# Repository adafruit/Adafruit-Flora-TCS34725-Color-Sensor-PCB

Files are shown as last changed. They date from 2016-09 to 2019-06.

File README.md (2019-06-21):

## Adafruit Flora TCS34725 Color Sensor PCB

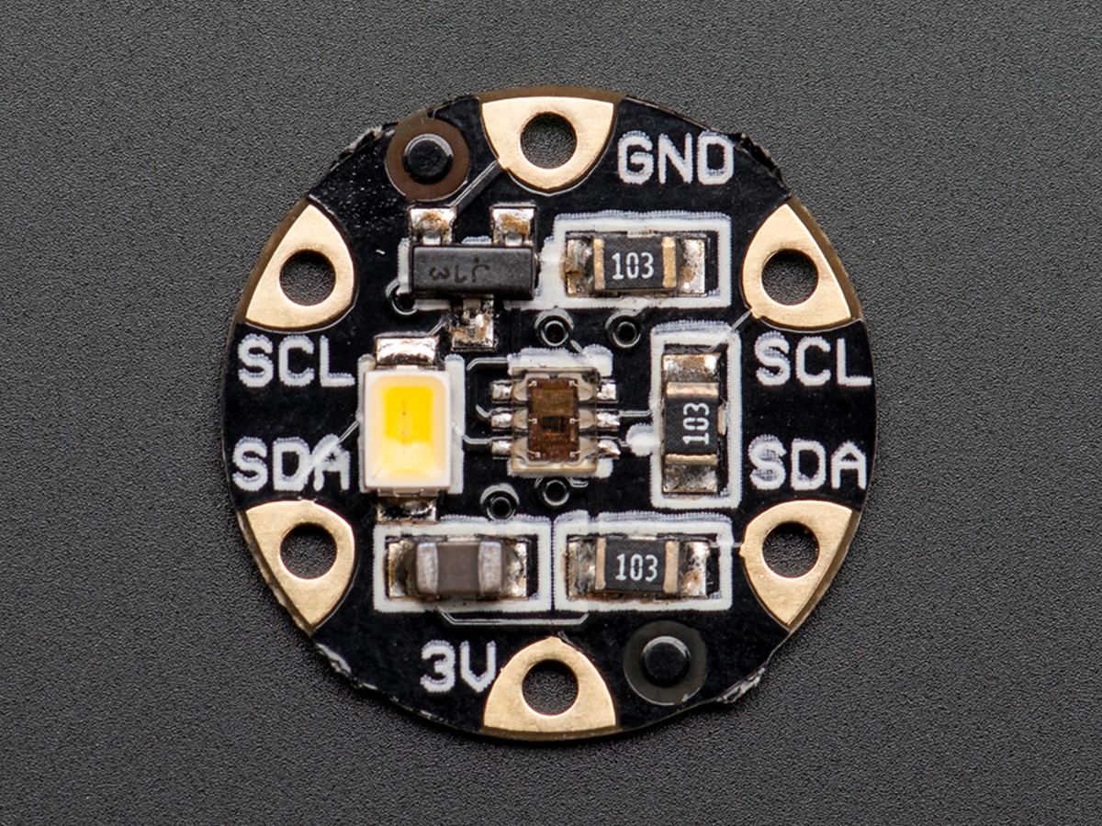
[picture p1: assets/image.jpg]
<a href="http://www.adafruit.com/products/1356"><br/>
Click here to purchase one from the Adafruit shop</a>

PCB files for the Adafruit Flora TCS34725 Color Sensor. Format is EagleCAD schematic and board layout
* https://www.adafruit.com/product/1356

### Description

Your electronics can now see in dazzling color with this lovely color light sensor. We found the best color sensor on the market, the TCS34725, which has RGB and Clear light sensing elements. An IR blocking filter, integrated on-chip and localized to the color sensing photodiodes, minimizes the IR spectral component of the incoming light and allows color measurements to be made accurately. The filter means you'll get much truer color than most sensors, since humans don't see IR. The sensor also has an incredible 3,800,000:1 dynamic range with adjustable integration time and gain so it is suited for use behind darkened glass or fabric.

To make sure you get consistent color, we specified a nice neutral 4150°K temperature LED with a MOSFET driver onboard to illuminate what you're trying to sense. The LED can be easily turned on during sensing and turned off afterwards to save power.

### License

Adafruit invests time and resources providing this open source design, please support Adafruit and open-source hardware by purchasing products from [Adafruit](https://www.adafruit.com)!

Designed by Limor Fried/Ladyada for Adafruit Industries.

Creative Commons Attribution/Share-Alike, all text above must be included in any redistribution. See license.txt for additional details.

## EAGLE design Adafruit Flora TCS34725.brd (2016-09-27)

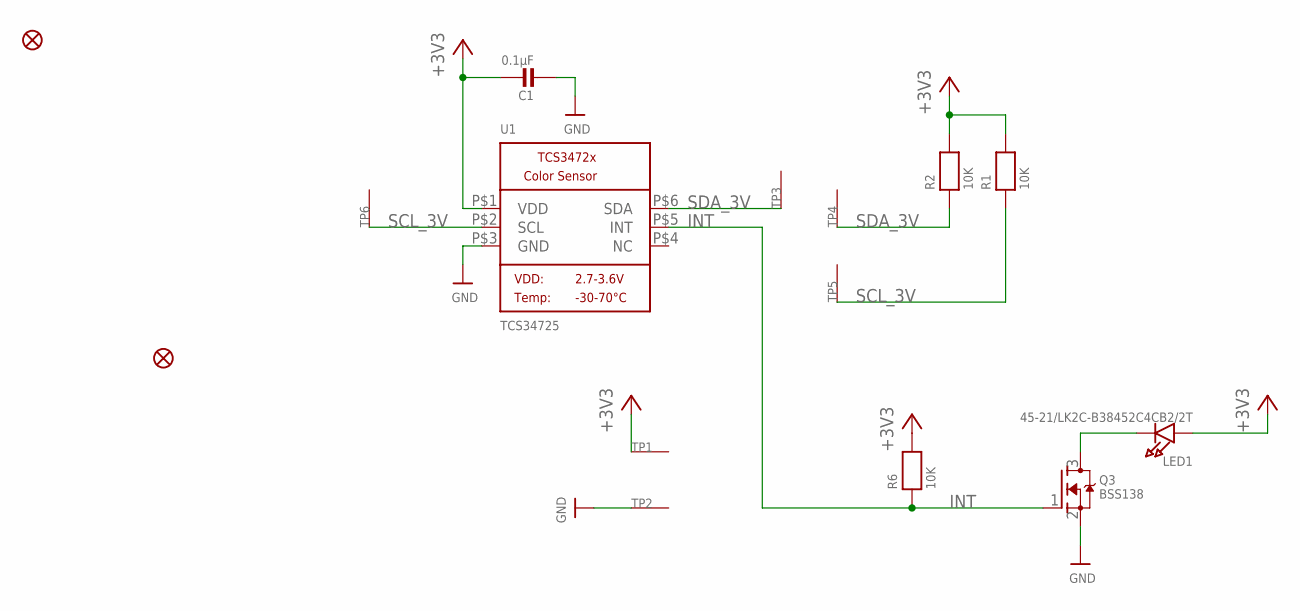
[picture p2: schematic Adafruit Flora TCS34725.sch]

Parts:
C1: 0.1µF; _0805
FID1, FID2: FIDUCIAL""; FIDUCIAL_1MM
LED1: 45-21/LK2C-B38452C4CB2/2T; EVERLIGHT_45-21
Q3: BSS138; SOT23-WIDE
R1, R2, R6: 10K; _0805
TP1, TP2, TP3, TP4, TP5, TP6: SEWTAP0.5IN; SEWINGTAP_0.5
U1: TCS34725; TCS3472_FN6

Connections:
+3V3: C1.1, LED1.A, R1.2, R2.2, R6.2, TP1.TAP, U1.P$1 (VDD)
GND: C1.2, Q3.2 (S), TP2.TAP, U1.P$3 (GND)
INT: Q3.1 (G), R6.1, U1.P$5 (INT)
unnamed: LED1.K (C), Q3.3 (D)
SCL_3V: R1.1, TP5.TAP, TP6.TAP, U1.P$2 (SCL)
SDA_3V: R2.1, TP3.TAP, TP4.TAP, U1.P$6 (SDA)

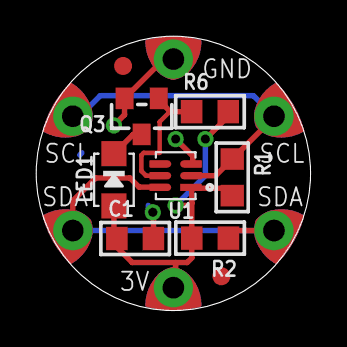
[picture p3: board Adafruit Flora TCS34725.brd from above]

Board: 2 copper layers, 15.2 x 15.2 mm, 16 parts (1 on the bottom side), 6 nets.

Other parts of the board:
U$8: ADAFRUIT_3.5MM

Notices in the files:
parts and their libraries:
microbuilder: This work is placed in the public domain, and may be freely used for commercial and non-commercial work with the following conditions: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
